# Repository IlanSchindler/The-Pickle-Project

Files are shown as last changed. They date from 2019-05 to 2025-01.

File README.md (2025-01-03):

# Pickle Project
#pickleProject

This project was from my Senior year of High School for an Independent Study Engineering class and the benefit of the school's marching band, which was an important part of my High School experience.

In addition to playing at home football games, the school's ~120 member marching band traveled to away games and competitions. 

We used a decommissioned school bus we called The Pickle to transport the larger instruments to and from these performances. To load the Pickle, we had many parents volunteer; they had to lift each instrument onto the bus one by one and strap them in using bungee cords. It was a long process that was taxing on the parents and required a lot of manpower to complete. 

To make this process faster and easier I designed carts that could hold multiple instruments, be rolled up a ramp into The Pickle, and locked in securely. 

In addition to designing the actual carts, this project required me to write several proposals including: to the school district for permission to modify The Pickle, to the teacher responsible for my independent study class for approval, and to the band directors.
I also solicited the band parents for funding.

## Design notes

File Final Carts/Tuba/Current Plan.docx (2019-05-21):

The tubas will be held in place using these.

https://www.mcmaster.com/#8834t156/=1bu5oa5

the strap will be fed through the handles on the tubas and tightened until the tubas are secure. One end of this mechanism has a fixed strap length and the other an adjustable one. The adjustable end will be mounted to the pickle in a more permanent fashion close to the seats. The fixed end will not be attached to the pickle, except when the tubas are in, allowing for its mounting location to be adjusted as needed. It will be held in by a carabineer.

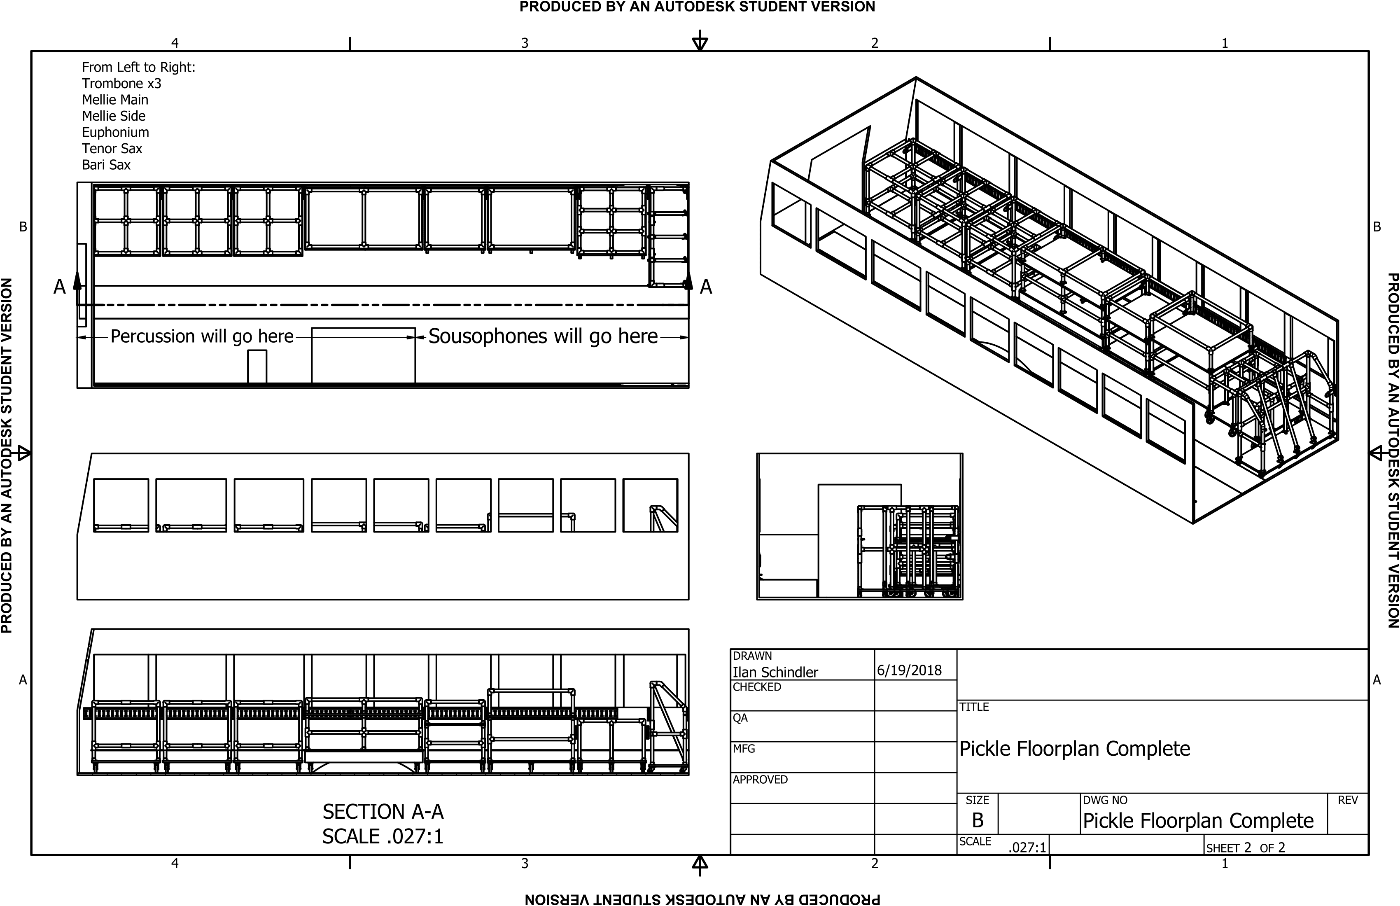
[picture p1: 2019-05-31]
Final Cart Sheets (PDF and PNG)/Pickle Floorplan Complete.png

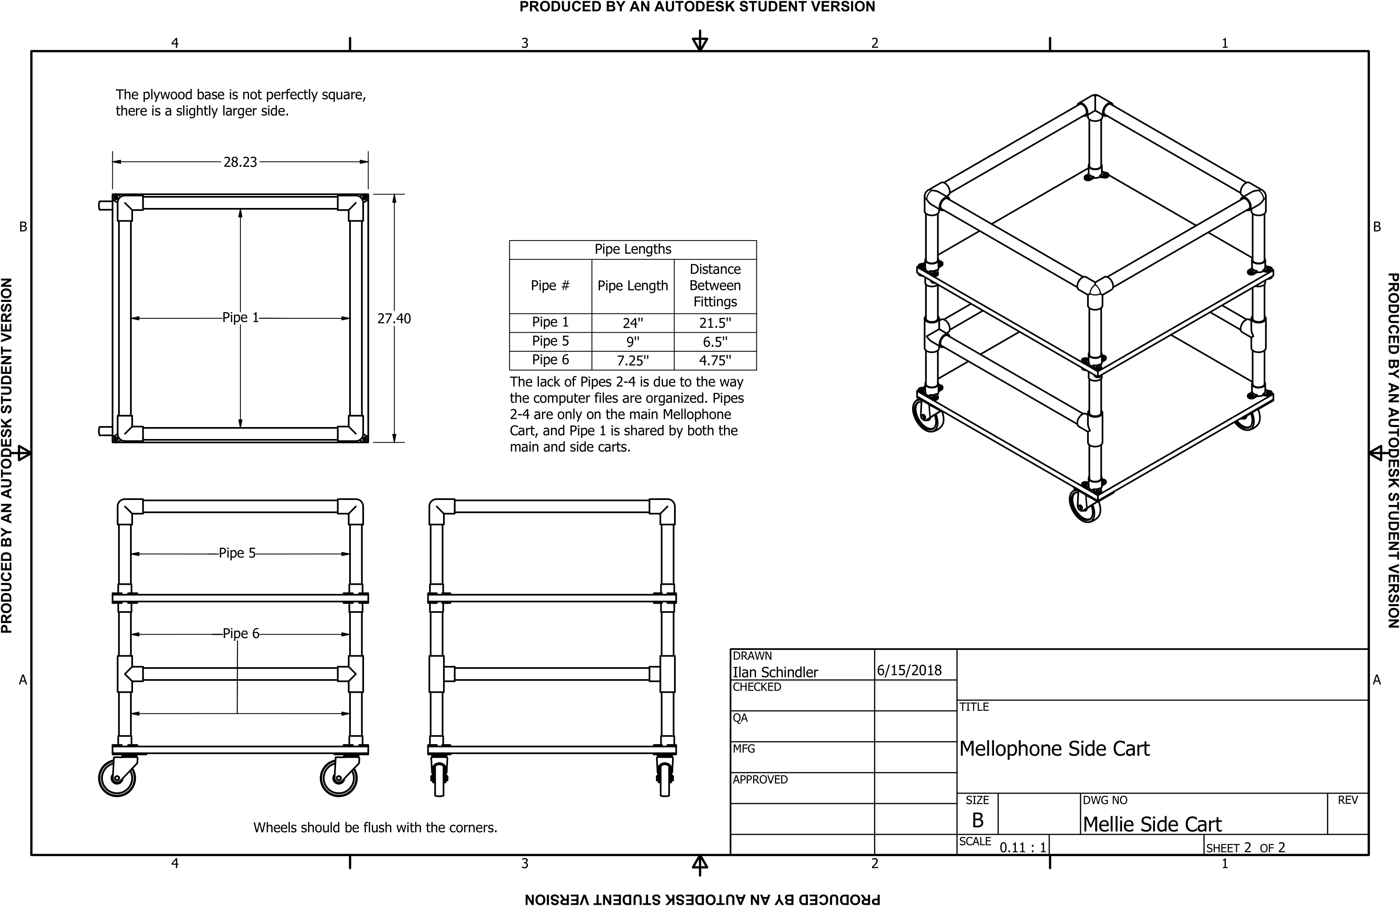
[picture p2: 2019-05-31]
Final Cart Sheets (PDF and PNG)/Mellie Side Cart.png

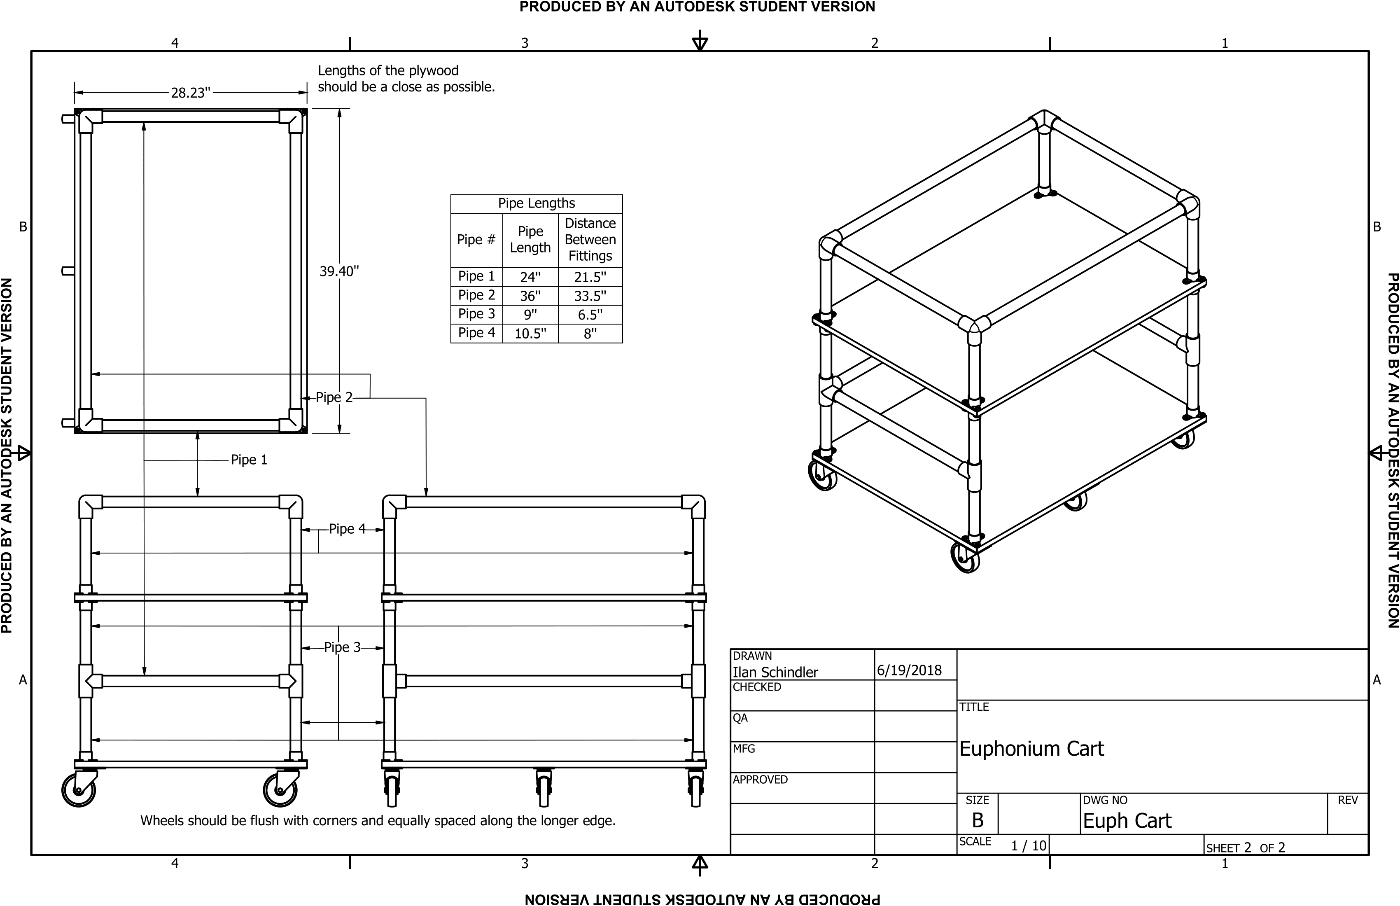
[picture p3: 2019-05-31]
Final Cart Sheets (PDF and PNG)/Euph Cart.png

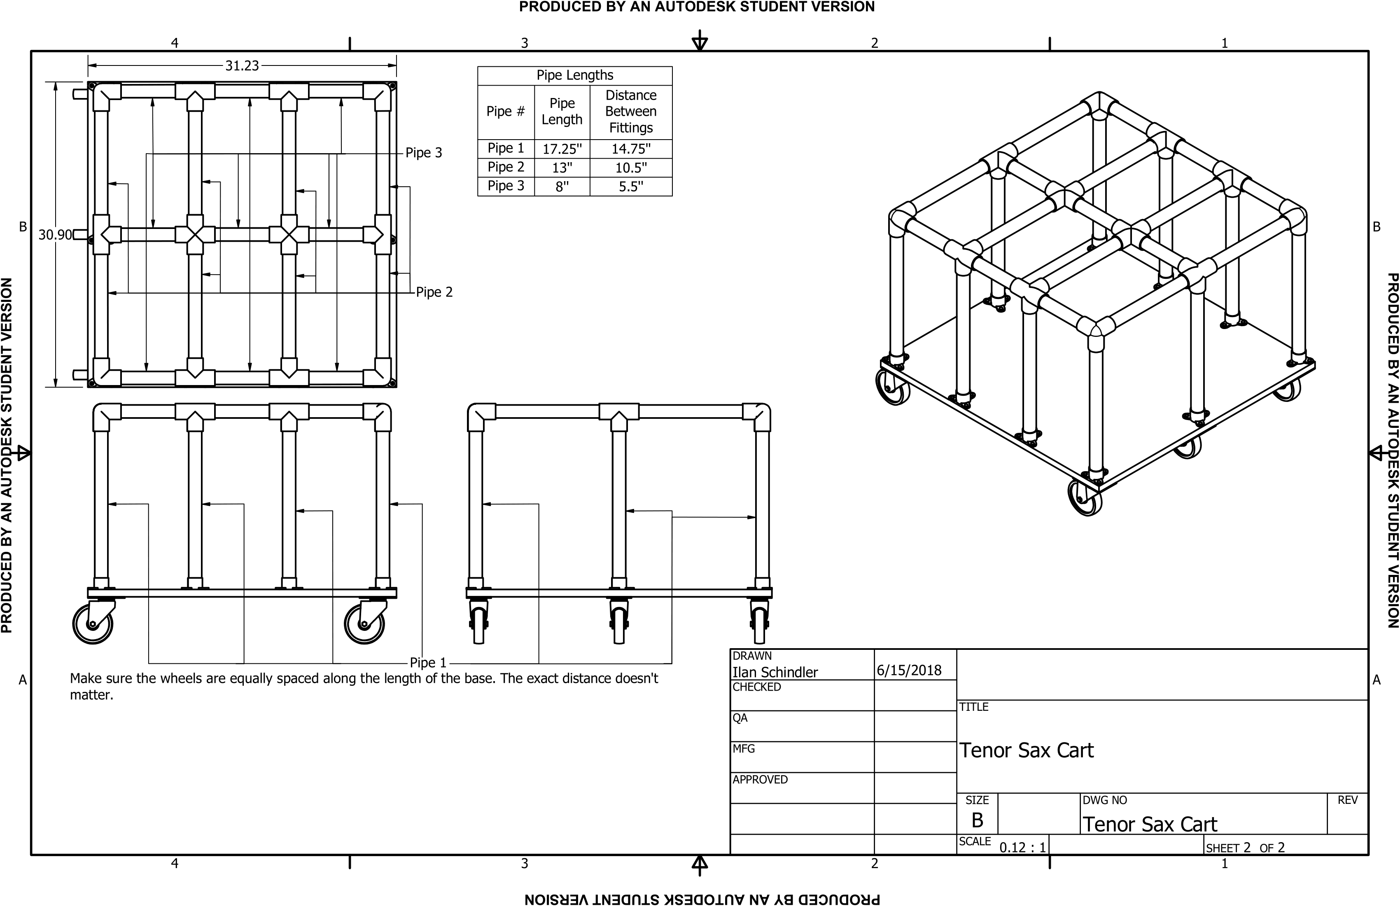
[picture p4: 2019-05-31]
Final Cart Sheets (PDF and PNG)/Tenor Sax Cart.png

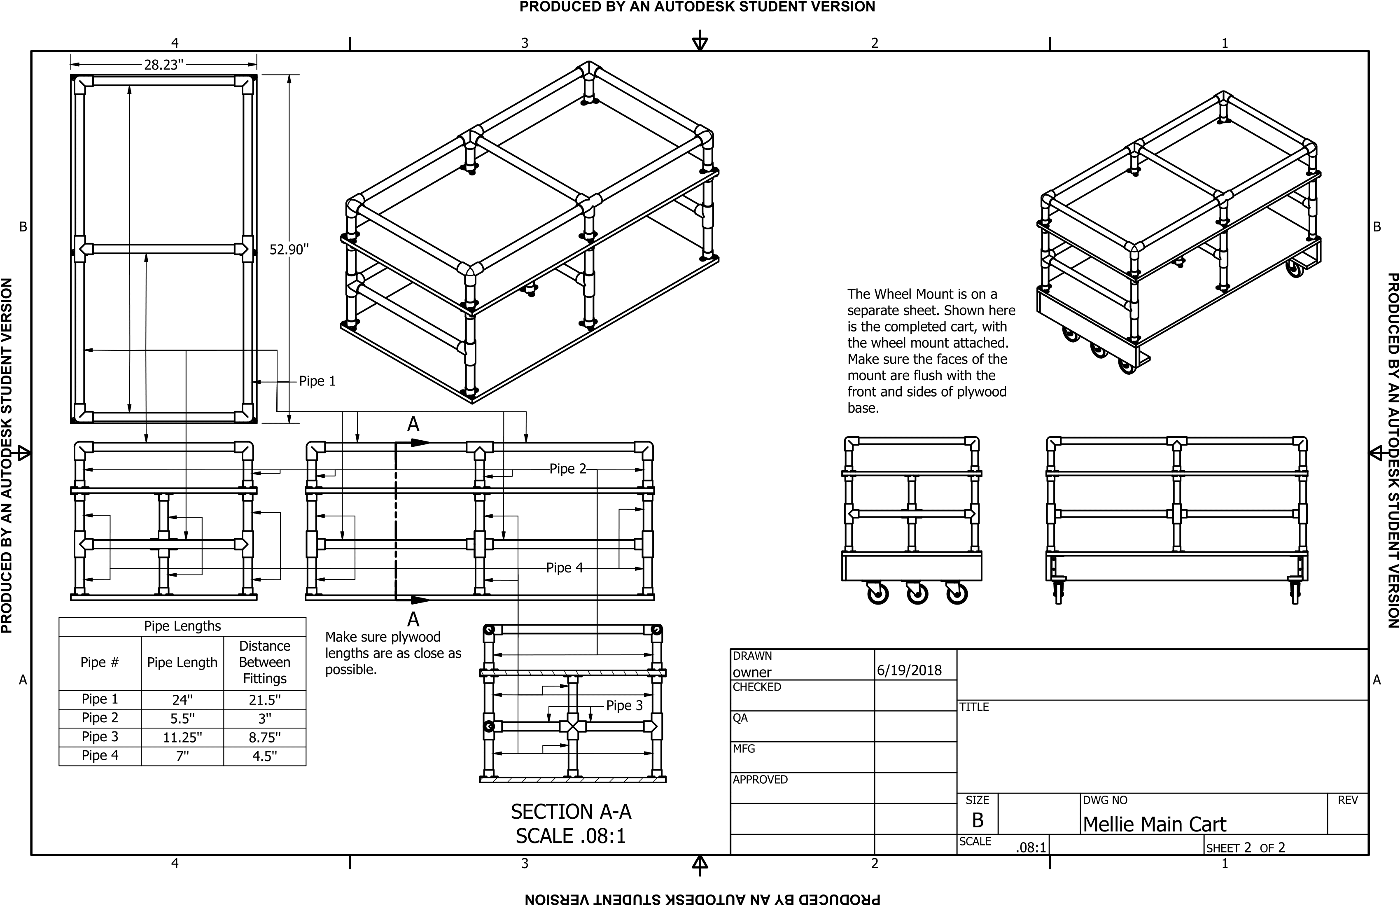
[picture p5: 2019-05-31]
Final Cart Sheets (PDF and PNG)/Mellie Main Cart.png

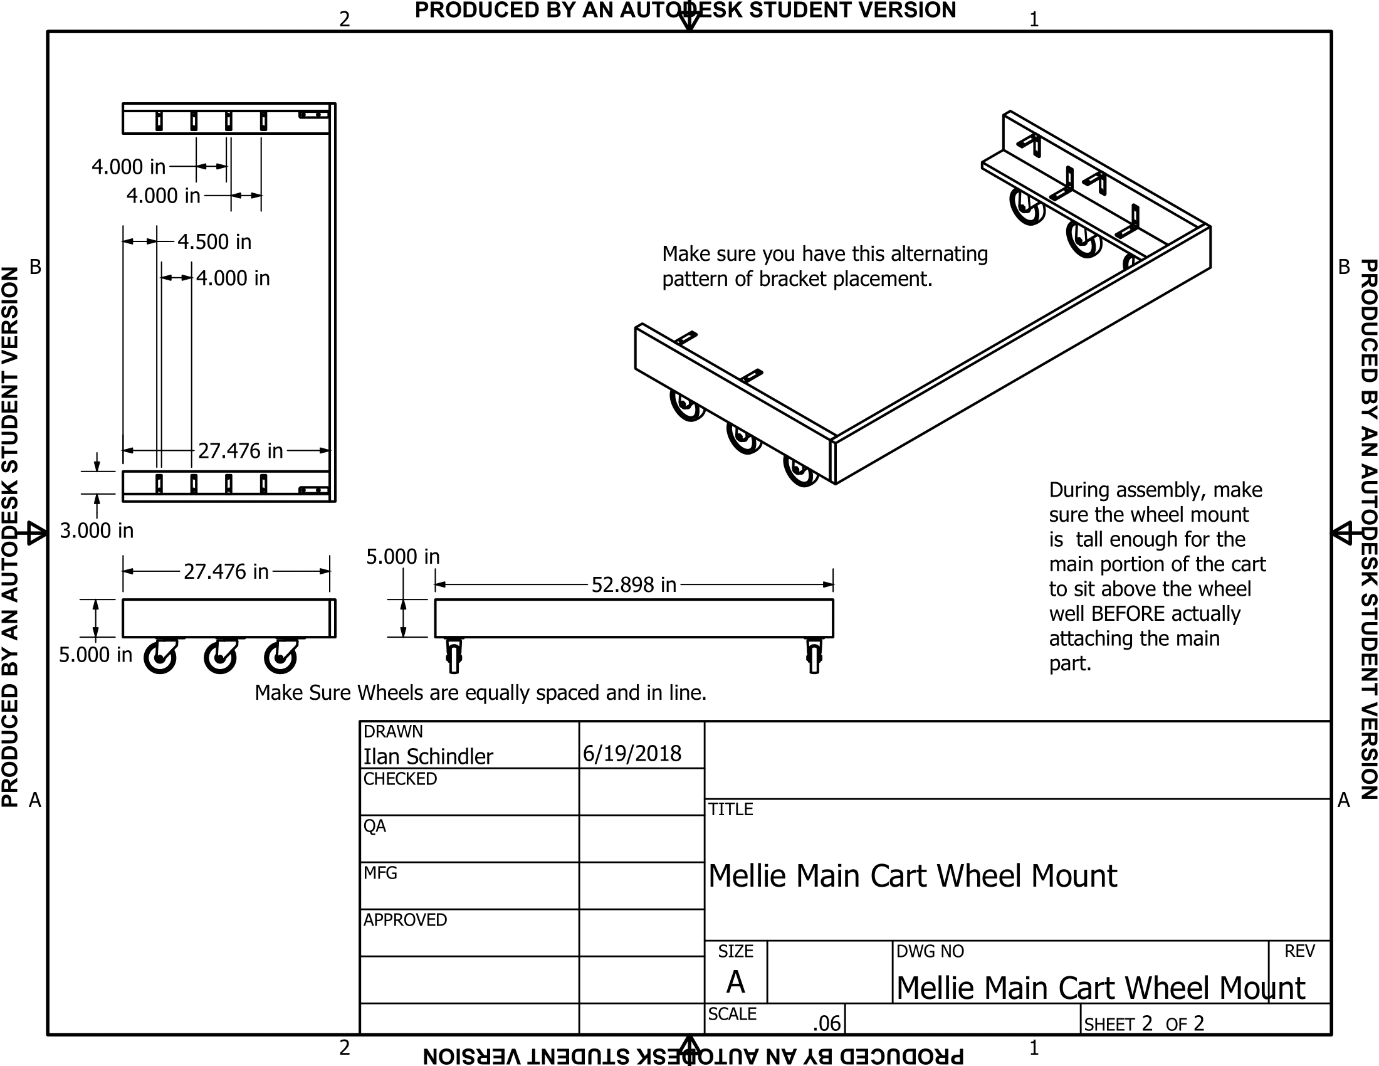
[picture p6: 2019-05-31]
Final Cart Sheets (PDF and PNG)/Mellie Main Cart Wheel Mount.png

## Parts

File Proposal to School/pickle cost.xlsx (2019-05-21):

Item | Carts |  |  |  |  |  |  | Mounts/Ramp | Totals | Cost/Unit | Total Cost for Materials
 | Trombone (per cart) | Trombone Total | Mellophone | Mellophone Side | Euphonium | Tenor Sax | Bari Sax
Total Plywood Area (sq.ft.) | 6.804 | 20.412 | 25.625 | 10.74 | 15.45 | 6.69 | 5.5 | 0 | 84.417 | $2.00 | $168.83
PVC Fittings
3 Way Corner | 4 | 12 | 4 | 4 | 4 | 4 | 2 | 0 | 30 | $2.15 | $64.50
Side outlet Tee (4 way) | 4 | 12 | 4 | 2 | 2 | 6 | 0 | 0 | 26 | $2.50 | $65.00
5 Way | 0 | 0 | 1 | 0 | 0 | 0 | 0 | 0 | 1 | $2.99 | $2.99
Tee | 8 | 24 | 3 | 2 | 2 | 0 | 6 | 0 | 37 | $1.70 | $62.90
Slip Tee | 0 | 0 | 0 | 0 | 0 | 0 | 5 | 0 | 5 | $2.05 | $10.25
Adjustable Elbow | 0 | 0 | 0 | 0 | 0 | 0 | 3 | 0 | 3 | $8.60 | $25.80
Cross | 2 | 6 | 1 | 0 | 0 | 2 | 2 | 0 | 11 | $2.30 | $25.30
Wood Mount | 4 | 12 | 20 | 12 | 12 | 10 | 9 | 0 | 75 | $1.90 | $142.50
45 Degree Elbow | 0 | 0 | 0 | 0 | 0 | 0 | 4 | 0 | 4 | $2.10 | $8.40
Total PVC Length (ft) | 37.75 | 113.25 | 37.6 | 23.45 | 28.125 | 31.79 | 37.84 | 0 | 272.055 | $0.33 | $89.78
Total Number Of Wheels | 4 | 12 | 6 | 4 | 6 | 6 | 0 | 0 | 34 | $10.20 | $346.80
Mounting Material
10ft Tracks | 0 | 0 | 0 | 0 | 0 | 0 | 0 | 4 | 4 | $33.88 | $135.52
Single Tracks | 0 | 0 | 0 | 0 | 0 | 2 | 2 | 0 | 4 | $4.78 | $19.12
Track Rings | 0 | 0 | 0 | 0 | 0 | 2 | 2 | 7 | 11 | $6.14 | $67.54
Tie Down Straps ( 10 pack) | 0 | 0 | 0 | 0 | 0 | 0 | 0 | 1 | 1 | $52.80 | $52.80
Paint (1 Gallon / 400 sq. ft) (Gal) | 0.017 | 0.051 | 0.064 | 0.027 | 0.039 | 0.017 | 0.014 | 0.000 | 0.211 | $31.48 | $31.48
Other Costs ($) | 0.00 | 0.00 | $16.80 | 0.00 | 0.00 | 0.00 | $77.78 | $1439.00 |  | $1.00 | $1533.58
 |  |  | Brackets for raised platform |  |  |  | Bungees/Wheels | Ramp and accessories
Total Costs (per cart) | $111.80 | $335.40 | $210.66 | $110.66 | $142.40 | $154.64 | $204.19 | $1670.30 |  |  | $2853.09

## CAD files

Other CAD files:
Final Carts/Sheets/Pickle Floorplan Complete AutoCAD.dwg
Final Carts/Sheets/Mellie Main Cart Wheel Mount AutoCAD.dwg
Final Carts/Sheets/Pickle Floorplan Complete.dwg
Final Carts/Sheets/Mellie Main Cart.dwg
Final Carts/Sheets/Mellie Main Cart Wheel Mount.dwg
Final Carts/Sheets/Mellie Main Cart AutoCAD.dwg
Final Carts/Sheets/Mellie Side Cart.dwg
Final Carts/Sheets/Tenor Sax Cart AutoCAD.dwg
Final Carts/Sheets/Pickle Interior Modifications.dwg
Final Carts/Sheets/Euph Cart.dwg
Final Carts/Sheets/Tenor Sax Cart.dwg
Final Carts/Sheets/Euph Cart AutoCAD.dwg
Final Carts/Sheets/Bari Sax Cart AutoCAD.dwg
Final Carts/Sheets/Bari Sax Cart.dwg
Final Carts/Sheets/Mellie Side Cart AutoCAD.dwg
Final Carts/Sheets/Pickle Interior Modifications AutoCAD.dwg
Final Carts/Sheets/T-Bone Cart.dwg
Final Carts/Sheets/T-Bone Cart AutoCAD.dwg
Final Carts/Euph Cart/Euph Cart.iam
Final Carts/Euph Cart/Euph Pipe 1.ipt
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

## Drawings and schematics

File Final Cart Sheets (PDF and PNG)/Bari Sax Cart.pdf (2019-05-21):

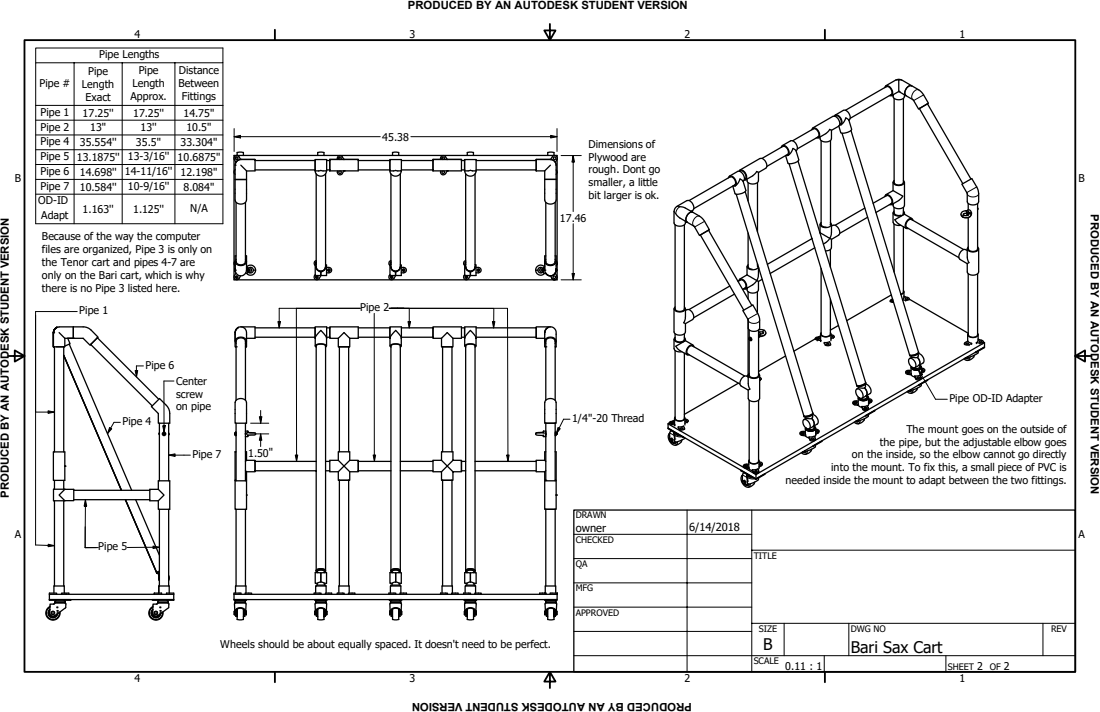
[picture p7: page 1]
REV; SCALE; SIZE; TITLE; owner; APPROVED; MFG; CHECKED; DRAWN; SHEET 2 OF 2; Pipe 5; Pipe 6; Pipe 4; Pipe 2; on pipe; screw; Center; 1/4''-20 Thread; N/A Adapt; Pipe 7 10.584''; Pipe 6 14.698''; Pipe 5 13.1875''; Pipe 4 35.554''; Pipe 1 17.25''; Fittings; Between; Distance; Approx.; Length; Pipe; Exact; Pipe #; Pipe Lengths

PRODUCED BY AN AUTODESK STUDENT VERSION

Dimensions of
Plywood are
rough. Dont go
smaller, a little
bit larger is ok.

Because of the way the computer
files are organized, Pipe 3 is only on
the Tenor cart and pipes 4-7 are
only on the Bari cart, which is why
there is no Pipe 3 listed here.
Pipe 1

Pipe OD-ID Adapter

The mount goes on the outside of
the pipe, but the adjustable elbow goes
on the inside, so the elbow cannot go directly
into the mount. To fix this, a small piece of PVC is

1.50'' Wheels should be about equally spaced. It doesn't need to be perfect.
Pipe 7

needed inside the mount to adapt between the two fittings.

DWG NO
Bari Sax Cart

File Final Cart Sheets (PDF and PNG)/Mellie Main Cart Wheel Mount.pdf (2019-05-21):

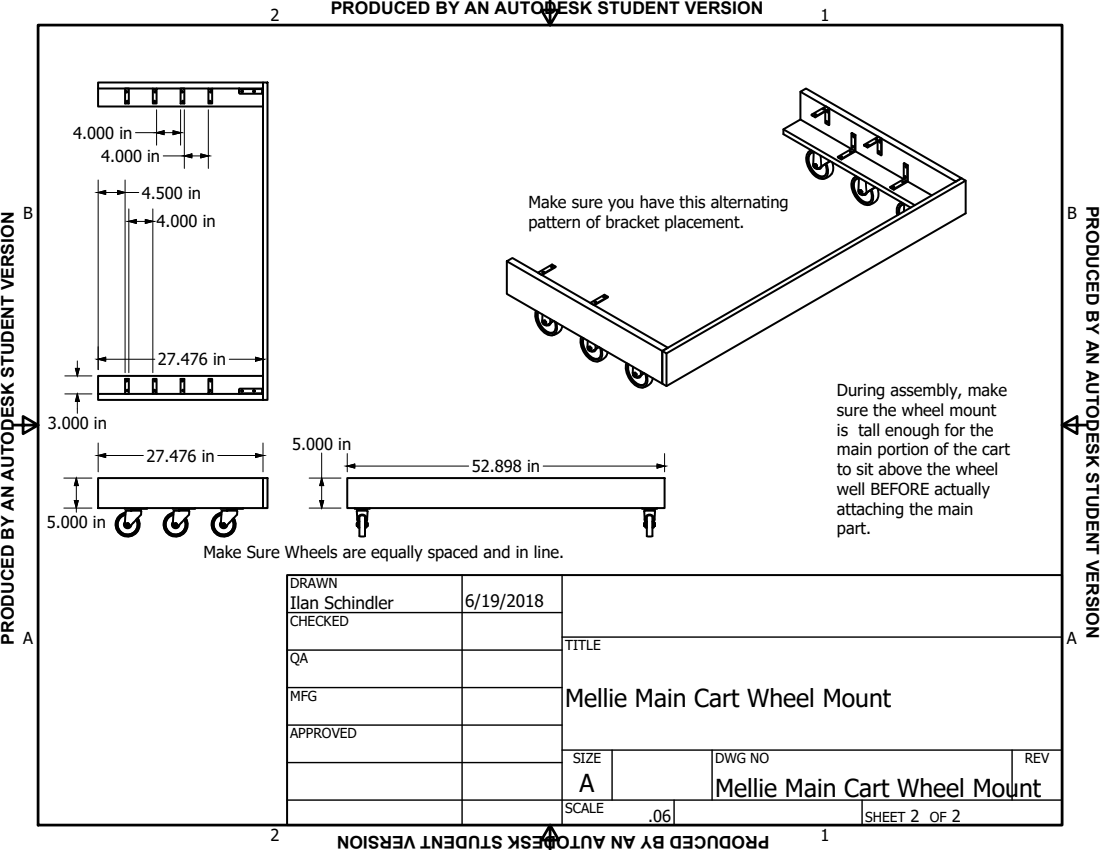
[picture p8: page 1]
B SHEET 2 OF 2 DRAWN CHECKED QAMFG APPROVED Ilan Schindler; DWG NO Mellie Main Cart Wheel Mount TITLE Mellie Main Cart Wheel Mount SIZE ASCALE; REV .06 27.476 in 5.000 in; Make Sure Wheels are equally spaced and in line. Make sure you have this alternating pattern of bracket placement.; During assembly, make sure the wheel mount is tall enough for the main portion of the cart to sit above the wheel well BEFORE actually attaching the main part.

PRODUCED BY AN AUTODESK STUDENT VERSION

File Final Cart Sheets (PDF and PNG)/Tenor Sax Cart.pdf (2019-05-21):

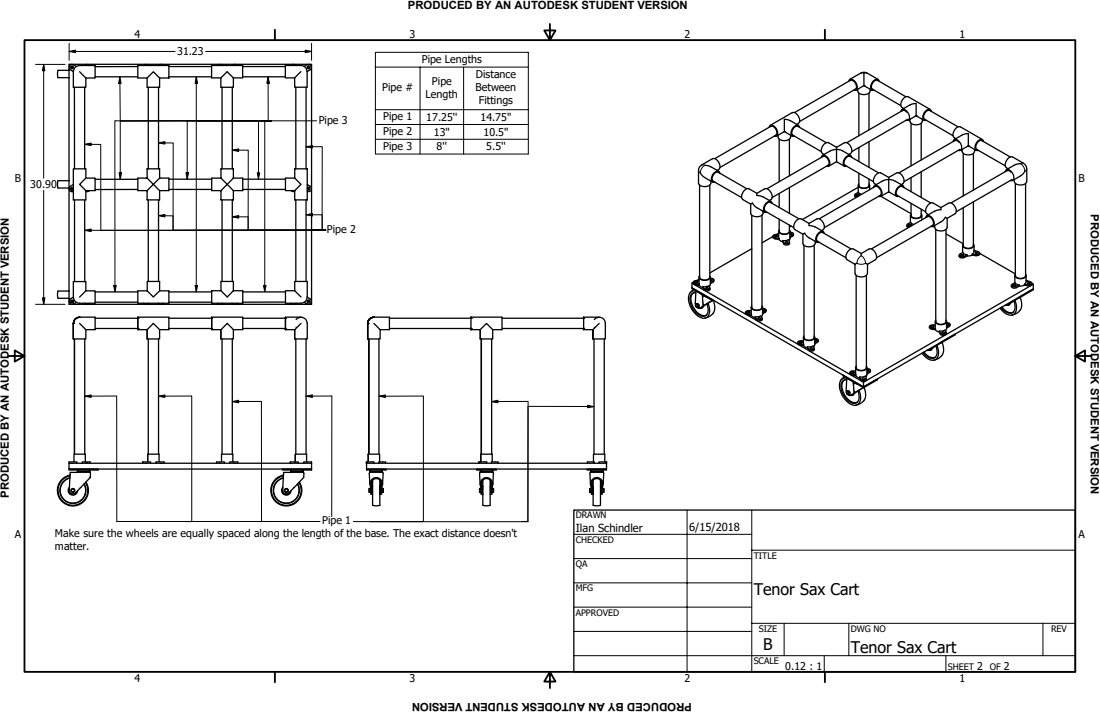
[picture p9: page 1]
REV; SCALE; SIZE; Ilan Schindler; APPROVED; MFG; CHECKED; DRAWN; SHEET 2 OF 2; Pipe 1; Pipe 2; Pipe 3; Fittings; Between; Distance; Length; Pipe Pipe #; Pipe Lengths

PRODUCED BY AN AUTODESK STUDENT VERSION

Make sure the wheels are equally spaced along the length of the base. The exact distance doesn't
matter.

TITLE
Tenor Sax Cart

DWG NO

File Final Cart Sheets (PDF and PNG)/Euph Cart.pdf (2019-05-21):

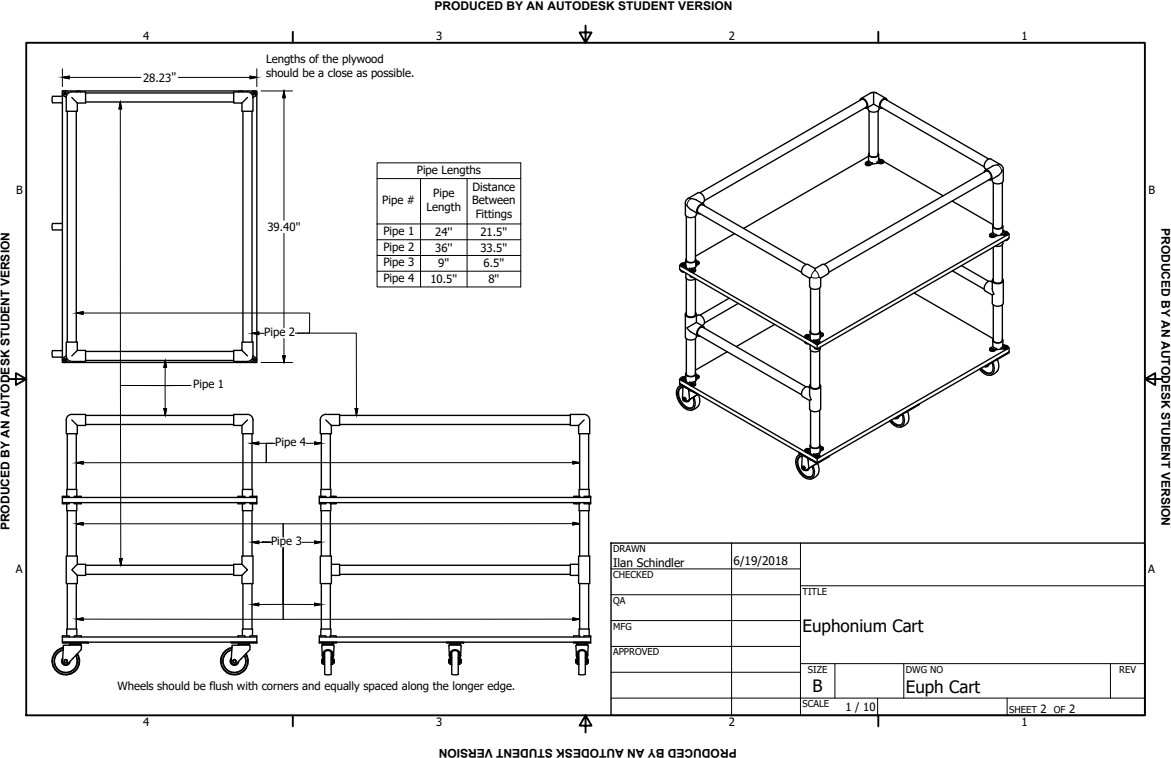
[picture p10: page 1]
REV SCALE BSIZE Euphonium Cart TITLE; Euph Cart DWG NO Ilan Schindler; 6/19/2018 APPROVED MFG QACHECKED DRAWN; SHEET 2 OF 2 Pipe 4 Pipe 3 Pipe 1; Pipe 2 28.23''; Pipe 4; 8'' Pipe 3; 6.5'' Pipe 2; 33.5'' Pipe 1; 21.5'' Fittings Between Distance Length Pipe Pipe #Pipe Lengths Wheels should be flush with corners and equally spaced along the longer edge. should be a close as possible. Lengths of the plywood

PRODUCED BY AN AUTODESK STUDENT VERSION

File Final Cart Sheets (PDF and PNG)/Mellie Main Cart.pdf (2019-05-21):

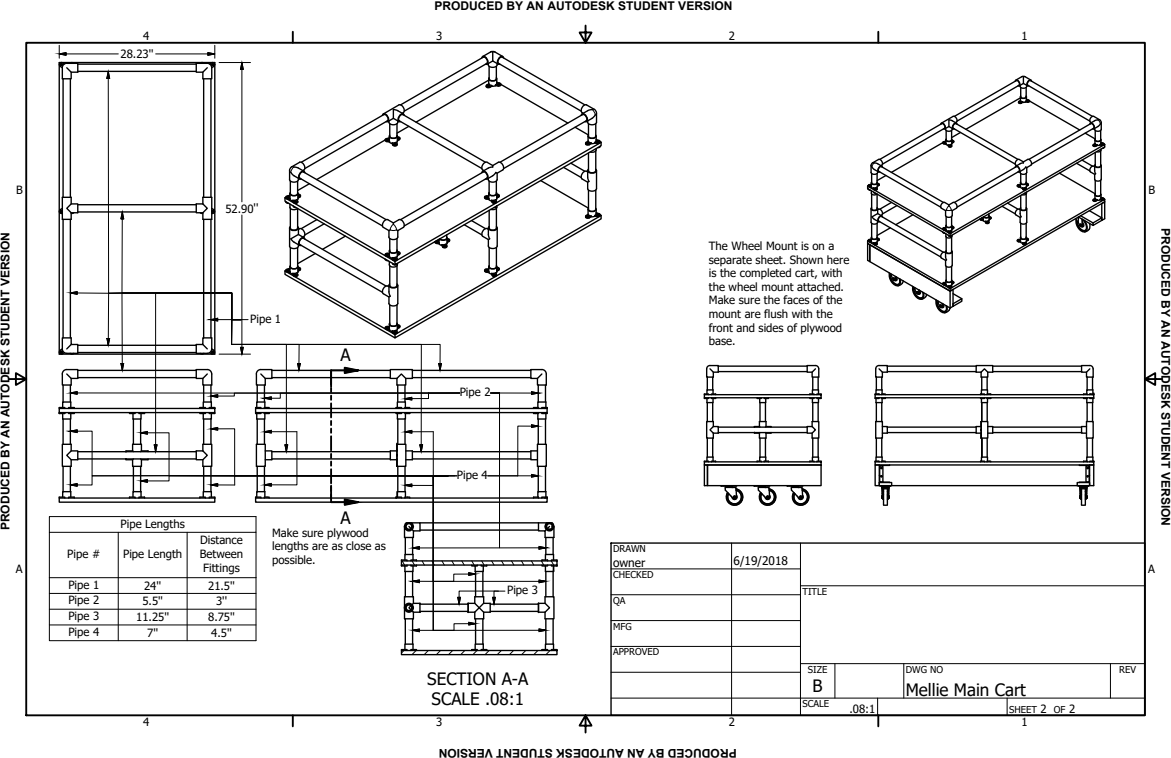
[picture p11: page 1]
REV SCALE BSIZE TITLE; Mellie Main Cart DWG NO owner; 6/19/2018 APPROVED MFG QACHECKED DRAWN; SHEET 2 OF 2 AA; SCALE .08:1 SECTION A-A Pipe 1; Pipe 2 Pipe 4; Pipe 3 28.23''; 52.90'' Pipe 4; 4.5'' Pipe 3; 8.75'' Pipe 2; 3'' Pipe 1; 21.5'' Fittings Between Distance Pipe #; Pipe Length Pipe Lengths; possible. lengths are as close as Make sure plywood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

PRODUCED BY AN AUTODESK STUDENT VERSION

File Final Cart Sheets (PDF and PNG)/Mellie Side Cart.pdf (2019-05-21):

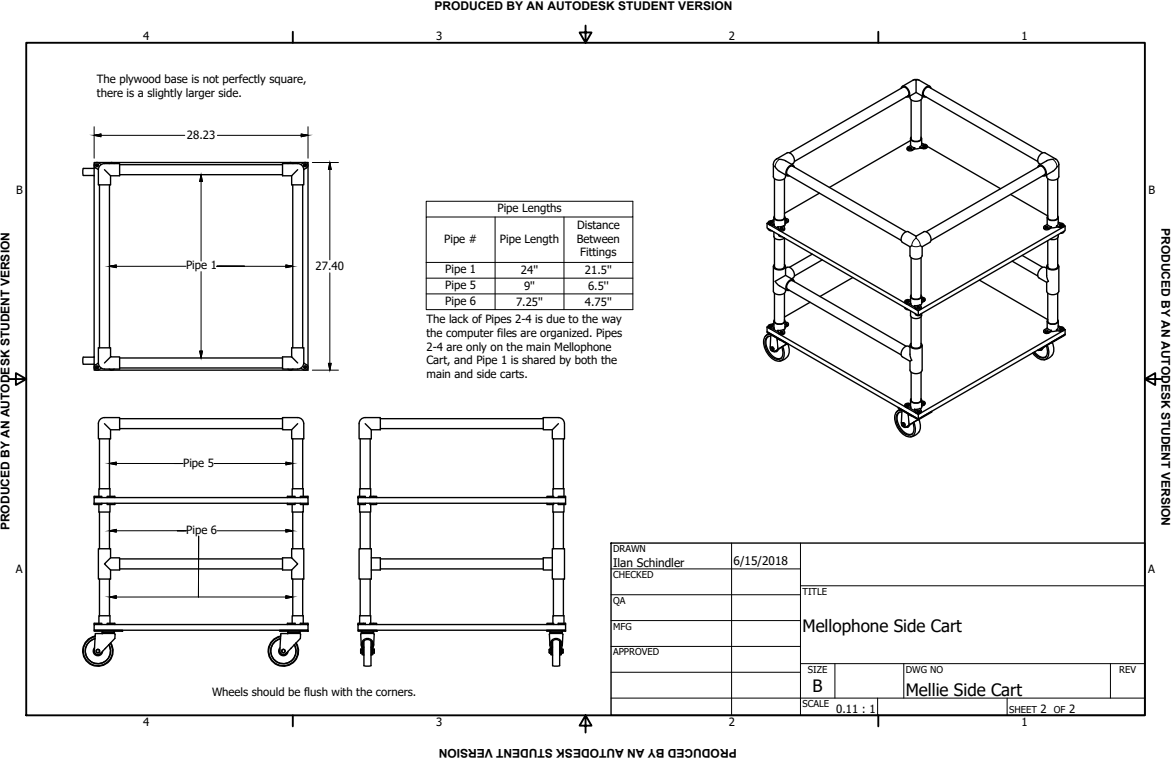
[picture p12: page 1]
REV SCALE BSIZE Mellophone Side Cart TITLE; Mellie Side Cart DWG NO Ilan Schindler; 6/15/2018 APPROVED MFG QACHECKED DRAWN; SHEET 2 OF 2 Pipe 6; 4.75'' Pipe 5; 6.5'' Pipe 1; 21.5'' Fittings Between Distance Pipe #; Pipe Length Pipe Lengths Pipe 1 Pipe 6 Pipe 5; 27.40 28.23Wheels should be flush with the corners. The plywood base is not perfectly square, there is a slightly larger side.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

PRODUCED BY AN AUTODESK STUDENT VERSION

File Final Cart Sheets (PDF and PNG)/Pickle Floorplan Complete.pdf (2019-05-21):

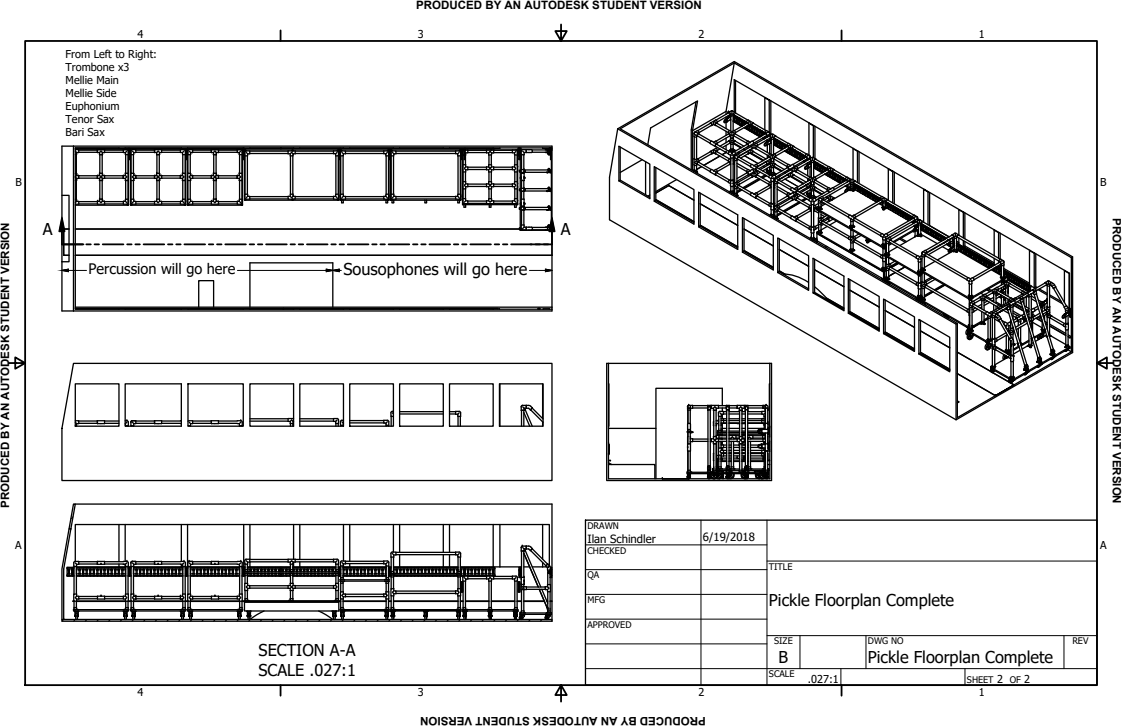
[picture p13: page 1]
REV SCALE BSIZE Pickle Floorplan Complete TITLE; Pickle Floorplan Complete DWG NO Ilan Schindler; 6/19/2018 APPROVED MFG QACHECKED DRAWN; SHEET 2 OF 2 A; A SCALE .027:1 SECTION A-A Bari Sax Tenor Sax Euphonium Mellie Side Mellie Main Trombone x3 From Left to Right: Percussion will go here; Sousophones will go here

PRODUCED BY AN AUTODESK STUDENT VERSION

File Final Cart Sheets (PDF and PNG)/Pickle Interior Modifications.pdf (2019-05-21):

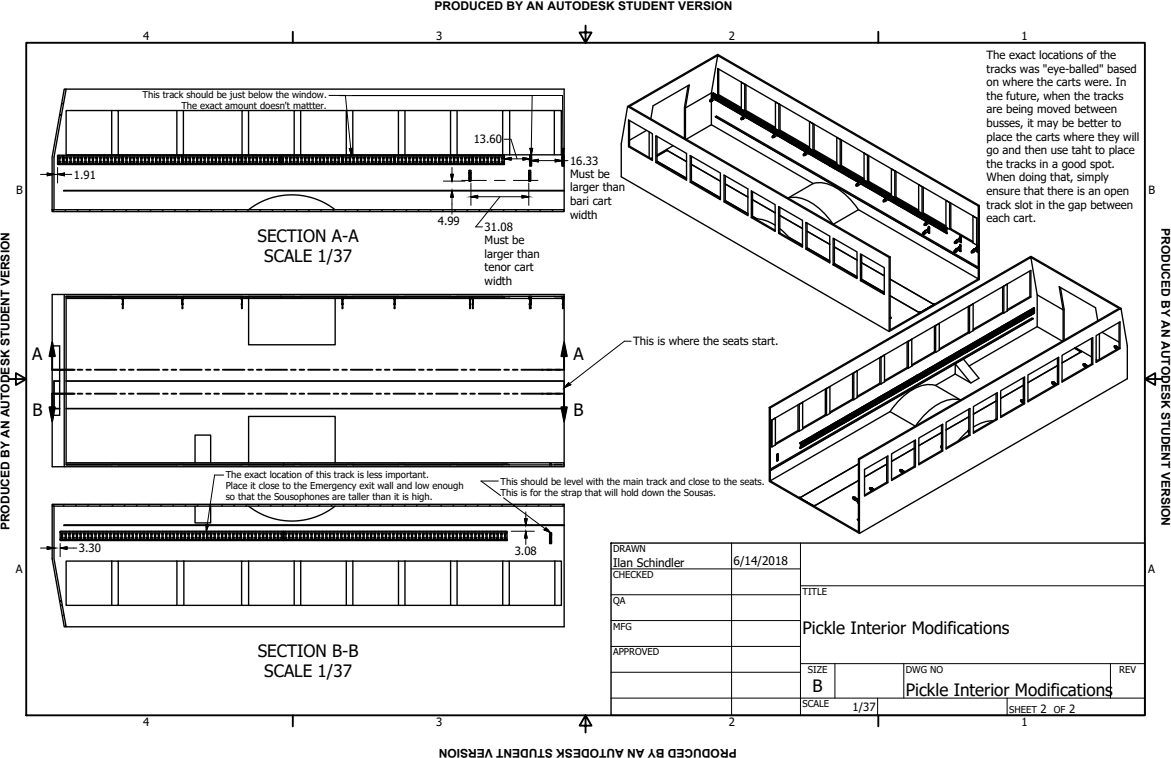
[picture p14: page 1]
REV SCALE BSIZE Pickle Interior Modifications TITLE; Pickle Interior Modifications DWG NO Ilan Schindler; 6/14/2018 APPROVED MFG QACHECKED DRAWN; SHEET 2 OF 2 A; A SCALE 1/37 SECTION A-A B; B SCALE 1/37 SECTION B-B The exact amount doesn't mattter. This track should be just below the window. 1.91; width bari cart larger than Must be 16.33 width tenor cart larger than Must be 31.08 4.99; This is where the seats start. 3.30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

PRODUCED BY AN AUTODESK STUDENT VERSION

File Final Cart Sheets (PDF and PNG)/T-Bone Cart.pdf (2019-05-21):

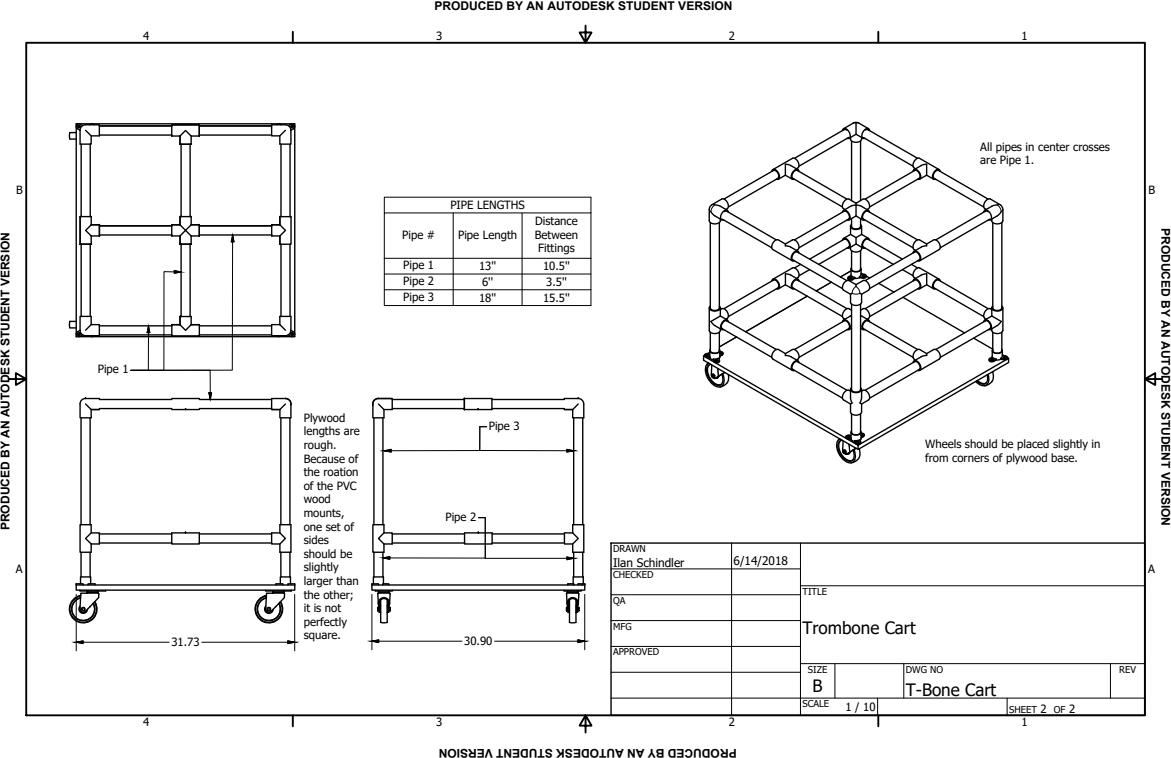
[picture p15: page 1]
REV SCALE BSIZE Trombone Cart TITLE; T-Bone Cart DWG NO Ilan Schindler; 6/14/2018 APPROVED MFG QACHECKED DRAWN; SHEET 2 OF 2 Pipe 1; Pipe 3 Pipe 2; are Pipe 1. All pipes in center crosses Pipe 3 Pipe 2; 3.5'' Pipe 1; 10.5'' Fittings Between Distance Pipe #; Pipe Length PIPE LENGTHS 18''; from corners of plywood base. Wheels should be placed slightly in 31.73; 30.90 square. perfectly it is not the other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

PRODUCED BY AN AUTODESK STUDENT VERSION
